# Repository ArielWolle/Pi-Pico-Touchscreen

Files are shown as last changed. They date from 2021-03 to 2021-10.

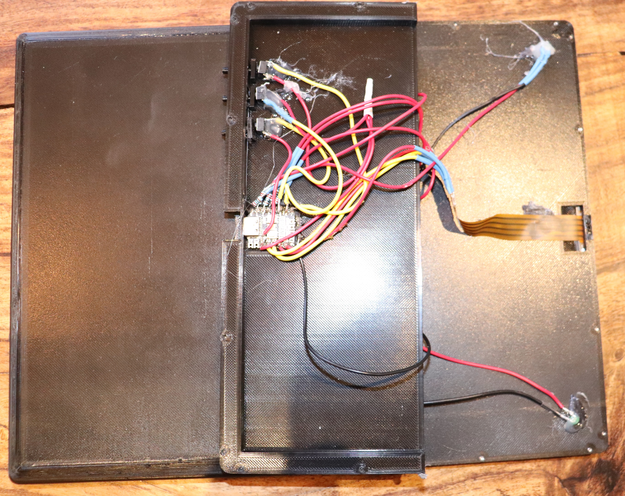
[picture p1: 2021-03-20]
Videos-Images/Wiring.jpg

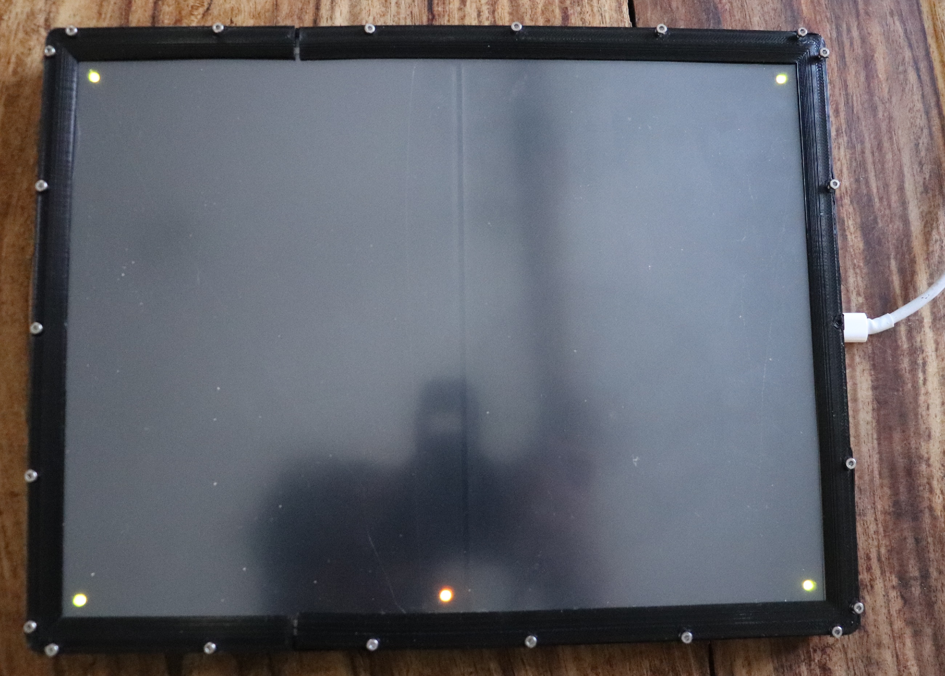
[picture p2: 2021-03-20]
Videos-Images/Lights_On.JPG

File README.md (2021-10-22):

# PI-Pico-Touchscreen

Custom touchscreen designed by me running off of a pimoroni tiny 2040 + 4 wire resistive touchscreen

Code is in the Touchscreen folder



## Prerequisites

Cirrcuitpython enabled device with 4 analog I/O (they need to be digital compatible as well), 7 digital IO, and a usb port with HID communication enabled.

4 wire resistive touchscreen (the one I got https://www.ebay.ca/itm/12-1inch-4-wire-Resistive-Touch-Panel-For-1024x768-1440x1050-4-3-LCD-Screen/180842889555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)

3 6x6 pushbutton switches

4 3mm green LED

1 3mm yellow LED

3D Printer

## Usage

This project is run off of adafruit's circuit python. 

You will need to make a new build of circuitpython to enable the digitizer (touchscreen). If running off of a pimoroni tiny 2040 a firmware build is included in the firmware folder.

On your circuitpython device you need to install the libraryies in the lib folder. 

Next copy the code.py onto the device.

Print enclosure

Assemble and wire up everything

Lastly draw to your hearts content.

## Known Bugs

## Next Steps

Make wiring diagram

Improving CAD as current 3d print looks bad.

Touchscreen wire placement

Build new firmware with the fix of (https://github.com/adafruit/circuitpython/issues/4417)

Drawing vid
https://user-images.githubusercontent.com/36164850/138474686-7877d604-5d39-49c1-bcea-47a5bc7aa096.mov

Calibration vid
https://user-images.githubusercontent.com/36164850/138474673-e01c95d1-a04b-4b8c-a8dc-2e1ca639f9e3.mov

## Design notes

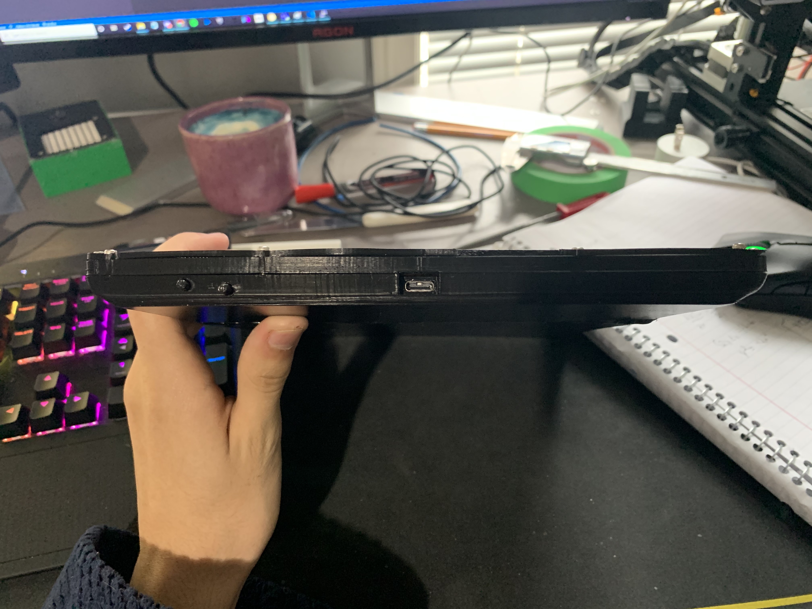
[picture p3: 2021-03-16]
Videos-Images/2021-03-16 14.16.52.jpeg

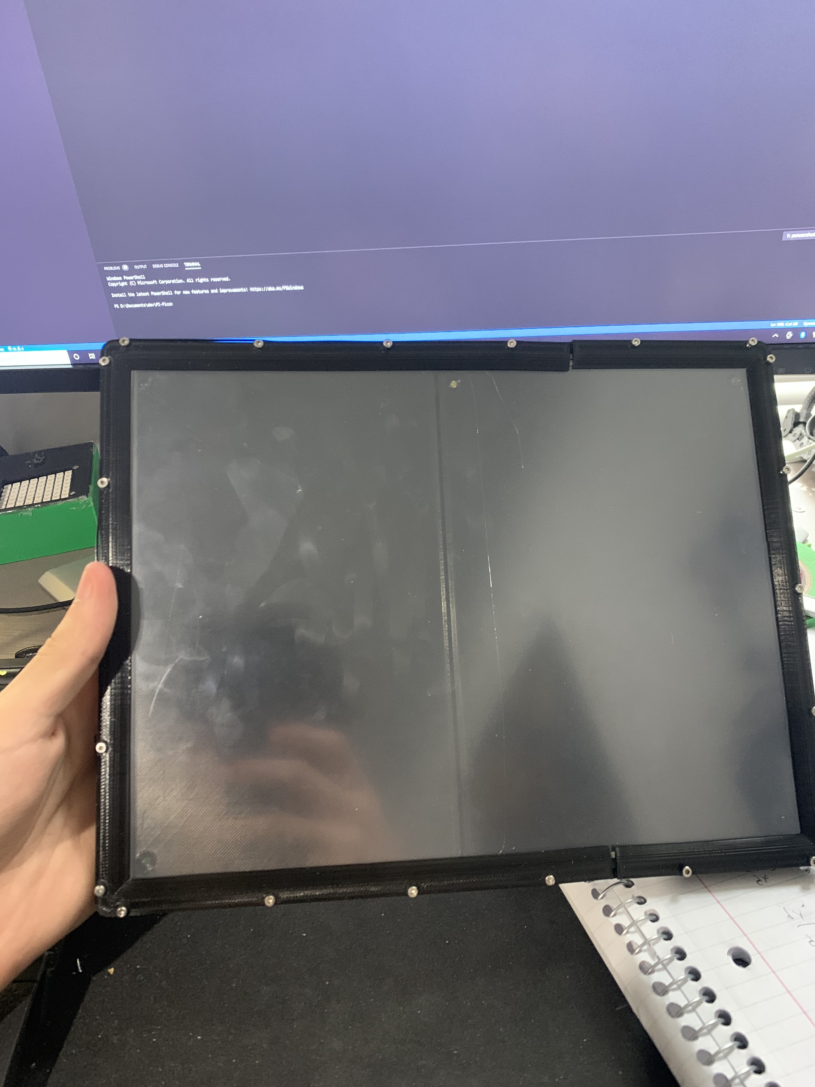
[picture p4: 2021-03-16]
Videos-Images/2021-03-16 14.16.36.jpeg

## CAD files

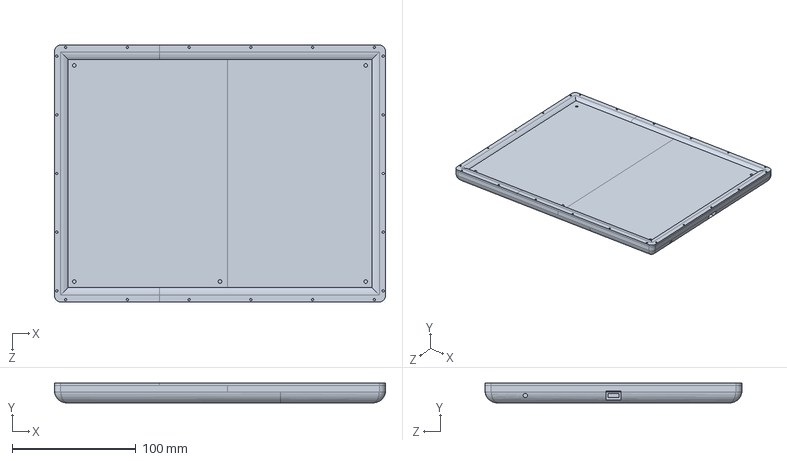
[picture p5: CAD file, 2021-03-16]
CAD/Solidworks/case.SLDPRT
268.0 x 16.0 x 208.0 mm

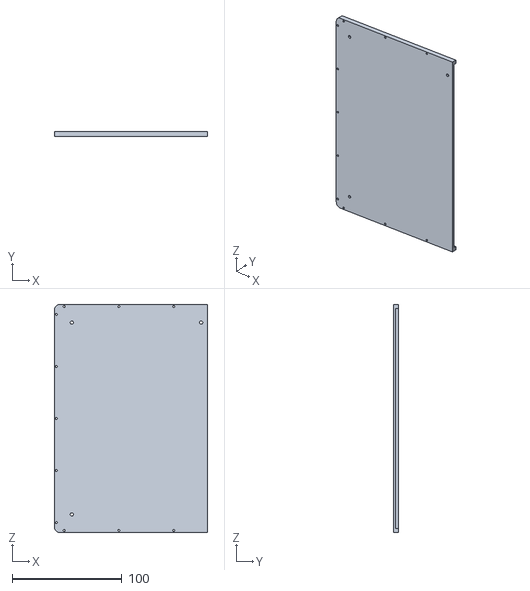
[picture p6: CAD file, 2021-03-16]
CAD/STL/Middle_No_Hole.STL
140.0 x 5.00 x 208.0

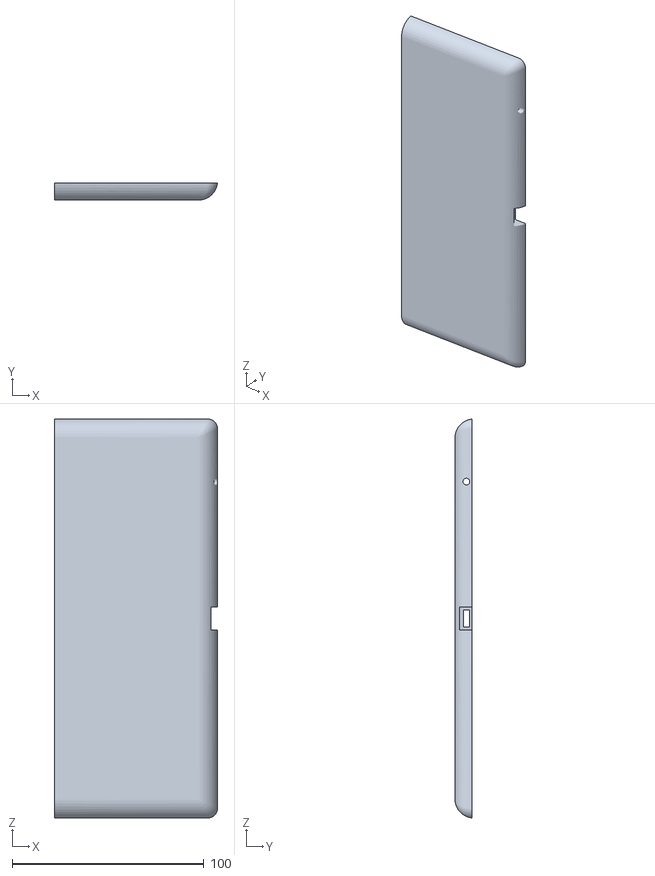
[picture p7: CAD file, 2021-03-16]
CAD/STL/Base_Hole_Side.STL
85.0 x 9.00 x 208.0

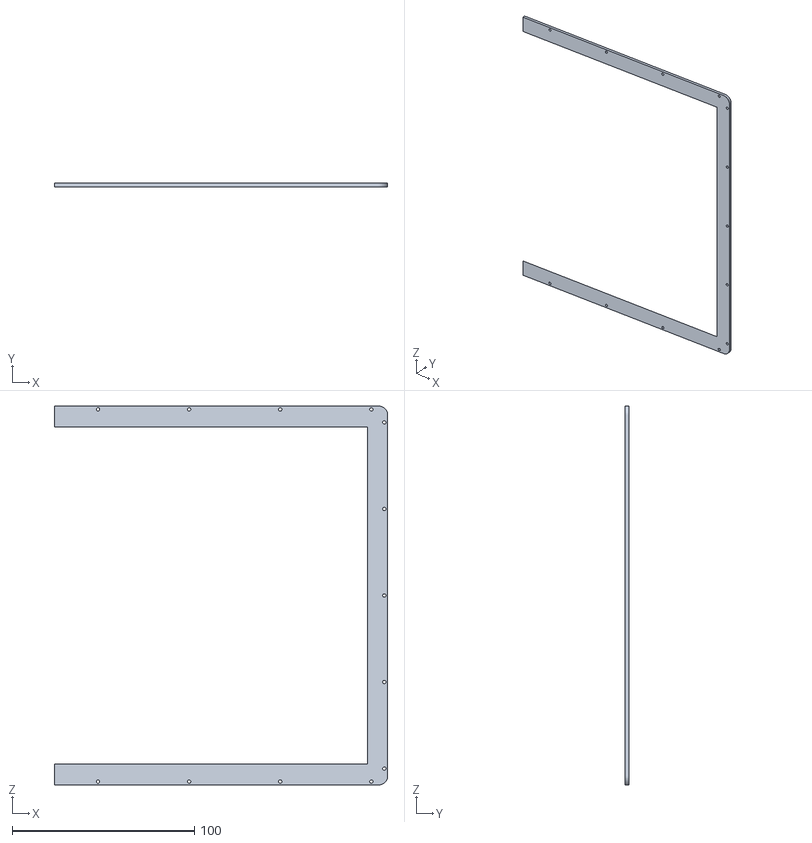
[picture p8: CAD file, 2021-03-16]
CAD/STL/Top_Hole.STL
183.0 x 2.00 x 208.0

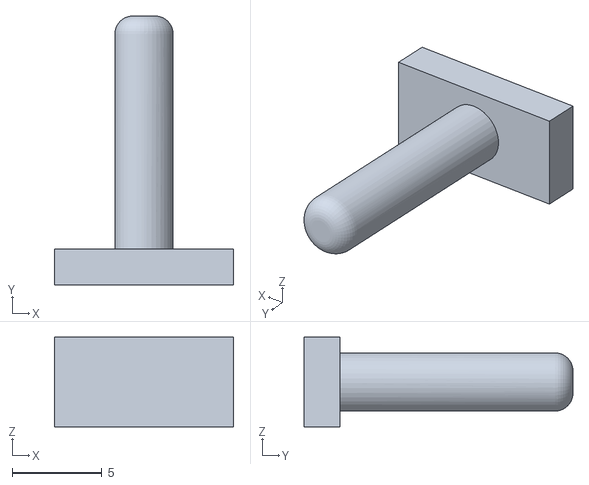
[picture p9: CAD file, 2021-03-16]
CAD/STL/pin.STL
10.0 x 15.0 x 5.00

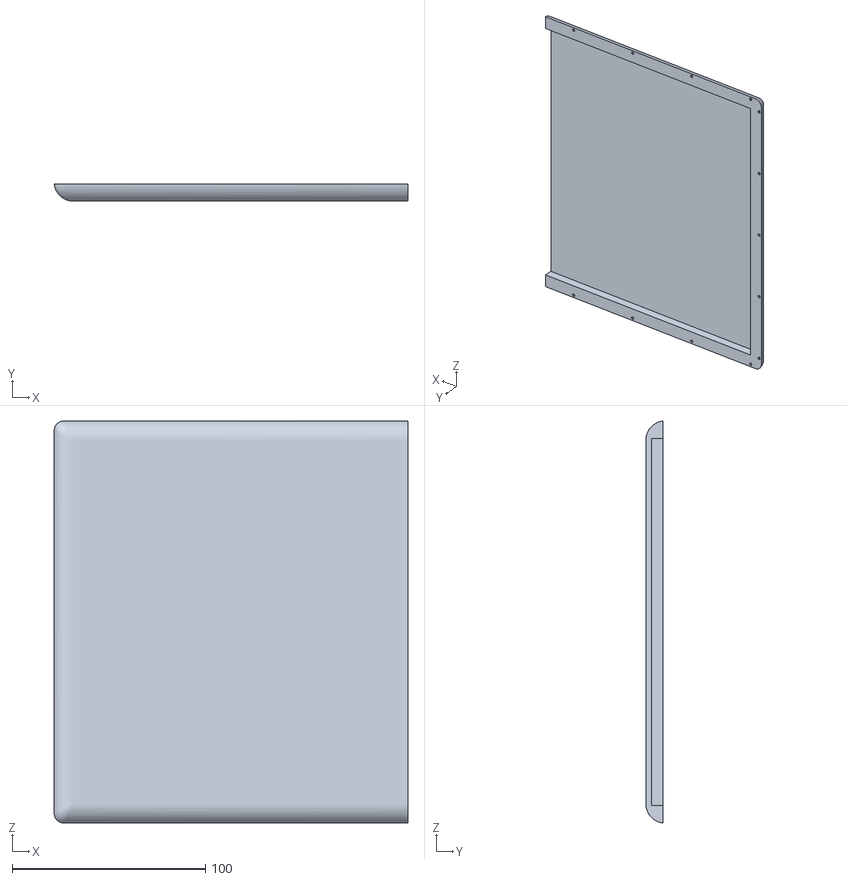
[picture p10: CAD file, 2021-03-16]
CAD/STL/Base_Non_Hole_Side.STL
183.0 x 9.00 x 208.0

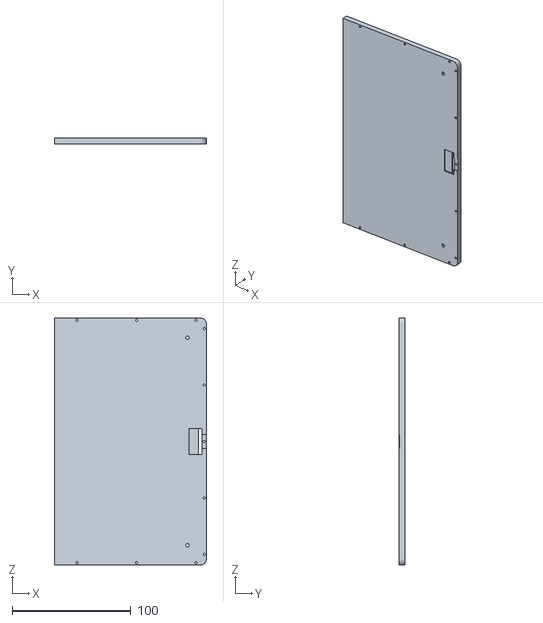
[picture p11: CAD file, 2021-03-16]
CAD/STL/Middle_Hole.STL
128.0 x 5.00 x 208.0

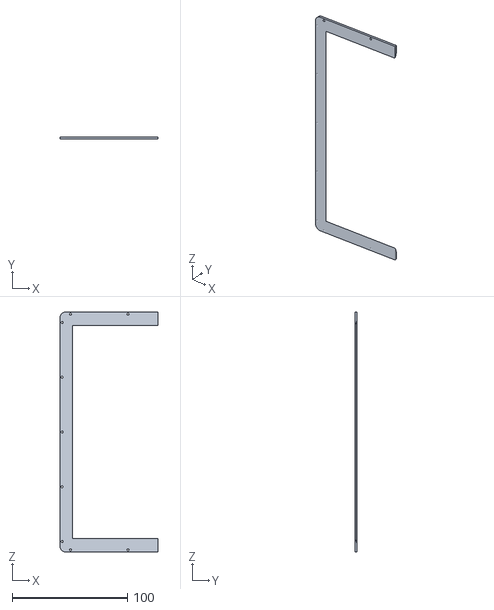
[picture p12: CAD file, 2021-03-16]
CAD/STL/Top_No_Hole.STL
85.0 x 2.00 x 208.0

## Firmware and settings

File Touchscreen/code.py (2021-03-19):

import time

import adafruit_touchscreen
import board
import digitalio
import usb_hid
import storage
import ulab
from adafruit_hid.digitizer import Digitizer

yelloww = digitalio.DigitalInOut(board.GP4)

top_L = digitalio.DigitalInOut(board.GP0)
top_R = digitalio.DigitalInOut(board.GP1)
bottom_L = digitalio.DigitalInOut(board.GP2)
bottom_R = digitalio.DigitalInOut(board.GP3)

switch = digitalio.DigitalInOut(board.GP6)
mode_sw = digitalio.DigitalInOut(board.GP7)
left_click = digitalio.DigitalInOut(board.GP5)

top_L.direction = digitalio.Direction.OUTPUT
top_R.direction = digitalio.Direction.OUTPUT
bottom_L.direction = digitalio.Direction.OUTPUT
bottom_R.direction = digitalio.Direction.OUTPUT
yelloww.direction = digitalio.Direction.OUTPUT

switch.direction = digitalio.Direction.INPUT
mode_sw.direction = digitalio.Direction.INPUT
left_click.direction = digitalio.Direction.INPUT

mode_sw.switch_to_input(pull=digitalio.Pull.DOWN)
left_click.switch_to_input(pull=digitalio.Pull.DOWN)
switch.switch_to_input(pull=digitalio.Pull.DOWN)

ts = adafruit_touchscreen.Touchscreen(board.A3, board.A1, board.A2, board.A0)


def startup():

    # Initial Start up sequence so that you know all is going well

    # Turn on all LEDS
    top_L.value = True
    top_R.value = True
    bottom_L.value = True
    bottom_R.value = True
    yelloww.value = True

    # Wait a second
    time.sleep(1)

    # Turn all LEDS off
    top_L.value = False
    top_R.value = False
    bottom_L.value = False

    bottom_R.value = False
    yelloww.value = False


def light_on(obj):

    # Helper method to turn on the LEDS

    obj.value = True


def light_off(obj):

    # Helper method to turn off LEDS

    obj.value = False


def solve(min, max):

    # Uses linear algebra to find the soloution of 2 linear equations

    a = ulab.array([[min, 1], [max, 1]])  # Stores the equation side of the matrix

    b = ulab.array([[0], [32726]])  # Stores the resultant side of the matrix

    x = ulab.linalg.dot(
        ulab.linalg.inv(a), b
    )  # Uses the formula inv(A) dot (B) = Soloution matrix

    return [x[0][0], x[1][0]]  # Returns soloution matrix


def calibration_loop():
    while True:
        if left_click.value:
            return 1
        p = ts.touch_point

        if p:
            if p[0] > 3000 and p[1] > 3000 and p[2] > 15000:
                return p


def calibration(old_data):
    # Calibration method

    # Calibrates the screen by having the user press the 4 corners of the touchscreen, the corner that is meant to be touched lights up with LEDS

    # Each corner press has 5 steps

    # Turn on the corressponding LED
    # Wait for touch input
    # Print the x,y,strength of the touch point to the serial com port
    # Turn off corresponding LED
    # Save the x and y values (automatically averages out min/max values)
    # Wait one second

    ############################

    # Start of corner touch calibration

    # TOP LEFT
    light_on(top_L)

    p = calibration_loop()
    if p == 1:
        return old_data

    print(p)
    light_off(top_L)
    x_min = p[0]
    y_min = p[1]
    time.sleep(1)

    # TOP RIGHT
    p = ts.touch_point
    light_on(top_R)

    p = calibration_loop()
    if p == 1:
        return old_data
    print(p)
    light_off(top_R)
    y_min = (y_min + p[1]) / 2
    x_max = p[0]
    time.sleep(1)

    # BOTTOM LEFT
    p = ts.touch_point

    light_on(bottom_L)
    p = calibration_loop()
    if p == 1:
        return old_data
    print(p)
    light_off(bottom_L)
    x_min = (x_min + p[0]) / 2
    y_max = p[1]
    time.sleep(1)

    # BOTTOM RIGHT
    p = ts.touch_point

    light_on(bottom_R)
    p = calibration_loop()
    if p == 1:
        return old_data
    print(p)
    light_off(bottom_R)
    x_max = (x_max + p[0]) / 2
    y_max = (y_max + p[1]) / 2
    time.sleep(1)

    # End of corner touch calibration

    #######################

    # Print the minimium and maximium values onto the serial com port
    print("X MIN: ", x_min)
    print("X MAX: ", x_max)
    print("Y MIN: ", y_min)
    print("Y MAX: ", y_max)

    # Use linear algebra to solve the system of two equations to conver the touchscreens 0-65xxx(max 12 bit ADC max value) to the digitizer 0-32767 values

    temp = solve(x_min, x_max) + solve(y_min, y_max)

    # Try to save the calibration data onto the flash memory

    # You need to eject the USB mass storage device with the current firmware build new firmware will be uploaded whent this issue is resolved https://github.com/adafruit/circuitpython/issues/4417

    try:
        storage.remount("/", False)  # Try mounting the storage to save

        # Saves the calibration data for the two y=mx+b as:
        # m1 b1\nm2 b2
        with open("/saved.txt", "w") as fp:
            fp.write(str(temp[0]) + " " + str(temp[1]) + "\n")
            fp.write(str(temp[2]) + " " + str(temp[3]))
            fp.close()
        storage.remount("/", True)  # Unmount the storage
    except:

        # If the calibration does not save the yellow LED flashes quickly 3 times but the calibration stays until next power cycle

        for i in range(3):
            light_on(yelloww)
            time.sleep(0.25)
            light_off(yelloww)
            time.sleep(0.25)

    return temp
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

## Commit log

2021-03-15 Added calibration filesystem
2021-03-15 added error catching when saving calibration
    [code.py]
2021-03-16 Changed LEDS
2021-03-16 removed random click bug
    [code.py]
2021-03-16 added CAD models
    [Base_Hole_Side.STL, Base_Non_Hole_Side.STL, Middle_Hole.STL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]
2021-03-17 Added Third Button
2021-03-18 fixed startup LED bug
    [code.py]
2021-03-19 fixed mode 2 errors
    [code.py]
